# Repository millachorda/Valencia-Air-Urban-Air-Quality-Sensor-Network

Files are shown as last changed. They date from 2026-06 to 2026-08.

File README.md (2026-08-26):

# Valencia Air — Urban Air Quality Sensor Network

Three DIY sensor nodes spread around Valencia, each one measuring the air in a
very different part of the city, all reporting to the same map.

**Live map:** https://valencia-air.milla-chorda.hackclub.app

> **TODO (write this part yourself):** why you started this. What made you want
> to measure the air here instead of just reading the official station data?
> Two or three sentences in your own words — this is the part a reader actually
> remembers, and nobody can write it for you.

---

## Status

Honest state of the project right now:

| Part | State |
|---|---|
| Backend (Flask + SQLite) | Works. Running on Nest. |
| Frontend (Leaflet map + Chart.js) | Works, fed by `/latest` and `/readings/<node>`. |
| Enclosure CAD | Done, parametric, STL + STEP exported. |
| ESP32 firmware | **Not written yet.** The map is currently fed by `backend/test_sender.py`, which posts fake readings. |
| Nodes deployed | 0 of 3. |

So: the whole software side is real and running, the hardware side is designed
but not yet built and flashed.

---

## The three nodes

| Node | Where | Why there |
|---|---|---|
| 1 | City center | Dense residential, narrow streets, not much wind |
| 2 | Periphery | Heavy traffic all day |
| 3 | Beach | Sea air, should be the clean reference |

> **TODO:** replace "City center" / "Periphery" / "Beach" with the actual
> streets or neighbourhoods, and say who is hosting each node (your balcony? a
> friend's window?). Reviewers care that these are real places.

Node 3 sits in constant marine humidity. The PMS5003 counts particles
optically, and above roughly 70 % RH the water on the particles makes them read
bigger than they are — so that node's PM values get corrected using the
humidity from its own BME280 before being stored.

---

## Hardware (per node)

Everything hangs off one ESP32. Four devices share the I2C bus, the particulate
sensor talks UART.

| Component | What it gives | Interface |
|---|---|---|
| ESP32 DevKit (USB-C) | MCU + WiFi | — |
| PMS5003 | PM1.0 / PM2.5 / PM10 in µg/m³ | UART, needs 5 V |
| BME280 | Temperature, humidity, pressure | I2C `0x76` |
| SCD41 | CO₂ in ppm (real NDIR, not estimated) | I2C `0x62` |
| SGP30 | VOC index | I2C `0x58` |
| 0.96" OLED | Shows the readings on the box itself | I2C `0x3C` |
| 5 V / 2 A USB-C supply | Power | — |

Full list with prices and suppliers: [`Hardware/BOM.csv`](Hardware/BOM.csv).

**Note on the two gas sensors:** the SCD41 is the one that measures CO₂
properly. The SGP30 is only there for VOC — its "eCO₂" output is an estimate
derived from VOC and is not used.

## Wiring

| Connection | ESP32 pin |
|---|---|
| SDA (BME280, SCD41, SGP30, OLED) | GPIO21 |
| SCL (BME280, SCD41, SGP30, OLED) | GPIO22 |
| PMS5003 TX → ESP32 | GPIO16 (RX2) |
| PMS5003 RX → ESP32 | GPIO17 (TX2) |
| BME280 / SGP30 / OLED VCC | 3V3 |
| PMS5003 VCC, SCD41 VDD | 5 V (VIN) |
| Everything GND | GND |

Diagram: [`Hardware/CAD/circuit_image.svg`](Hardware/CAD/circuit_image.svg)

---

## Enclosure

A commercial IP65 box (150 × 110 × 70 mm) with three printed parts inside it:
a tray that holds the boards, a bezel for the OLED, and a duct that feeds
outside air to the PMS5003.

Everything lives in [`Hardware/CAD/`](Hardware/CAD):

| File | What it is |
|---|---|
| `valencia_air_enclosure.py` | **Source.** CadQuery script, all dimensions parametric at the top. |
| `mounting_plate.stl` | Print this — interior tray |
| `oled_bezel.stl` | Print this — display frame |
| `pms_duct.stl` | Print this — air duct |
| `valencia_air_node.step` | All three parts in one STEP, positioned as they sit in the box |

To regenerate the STL and STEP files after changing a dimension:

```bash
pip install cadquery
python Hardware/CAD/valencia_air_enclosure.py
```

The parameters marked `[VERIFICAR]` in the script are the ones I could not
confirm against a datasheet — measure your own modules with calipers before
printing, generic boards vary between batches.

The renders in [`Hardware/Images/`](Hardware/Images) are the earlier Tinkercad
mockup, kept only to show how the layout started. The CadQuery script is the
real design.

---

## Assembly

Step by step build instructions, around 2 h per node:
**[`Hardware/ASSEMBLY.md`](Hardware/ASSEMBLY.md)**

---

## Software

### Backend — `backend/`

Flask + SQLite. One table, `readings`, one row per measurement.

```bash
cd backend
pip install flask flask-cors requests
python init_db.py        # creates readings.db
python app.py            # serves on :5000
```

| Route | Method | Does |
|---|---|---|
| `/` | GET | Serves the map |
| `/data` | POST | A node sends a reading (JSON) |
| `/readings` | GET | Everything |
| `/latest` | GET | Last reading of each node — this is what the map markers use |
| `/readings/<node>` | GET | History of one node, for the charts |

With no hardware built yet, you can fill the database with fake readings:

```bash
python backend/test_sender.py
```

### Frontend — `frontend/index.html`

One HTML file. Leaflet for the map, Chart.js for the history panel that opens
when you click a node. No build step, no framework.

### Firmware — not written yet

Planned: Arduino on the ESP32, using `Adafruit_BME280`, `Adafruit_SGP30`,
`Sensirion SCD4x`, `PMS` and `Adafruit_SSD1306`, POSTing JSON to `/data` in the
same shape `test_sender.py` uses.

---

## What's left

- [ ] Write the ESP32 firmware
- [ ] Print the three parts and build node 1
- [ ] Find hosts for nodes 2 and 3
- [ ] Deploy and let it run

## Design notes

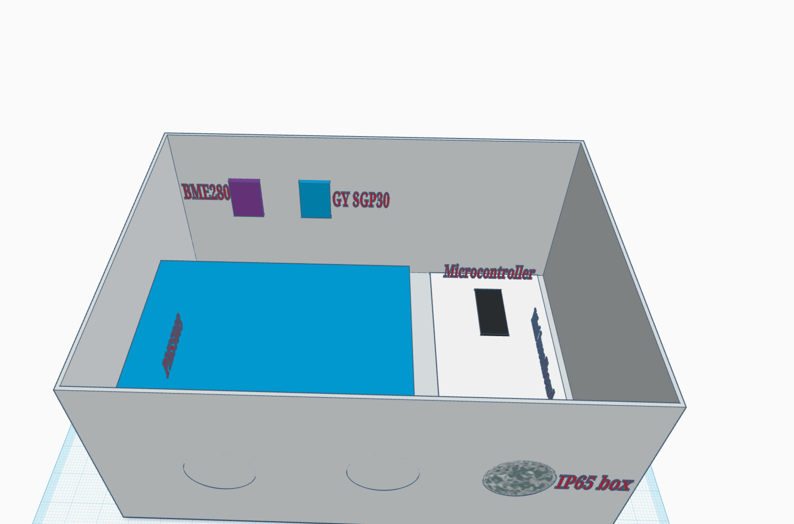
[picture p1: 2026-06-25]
Hardware/Images/Captura de pantalla 2026-06-25 162358.png

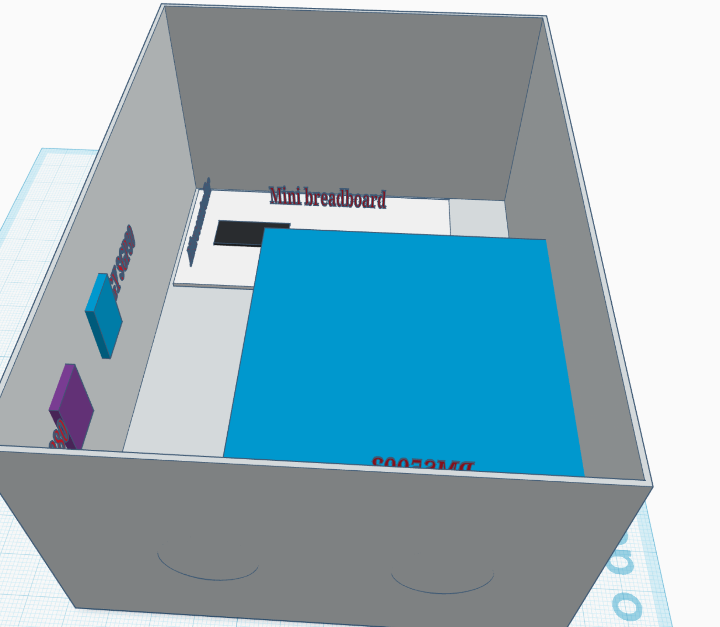
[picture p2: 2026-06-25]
Hardware/Images/Captura de pantalla 2026-06-25 162418.png

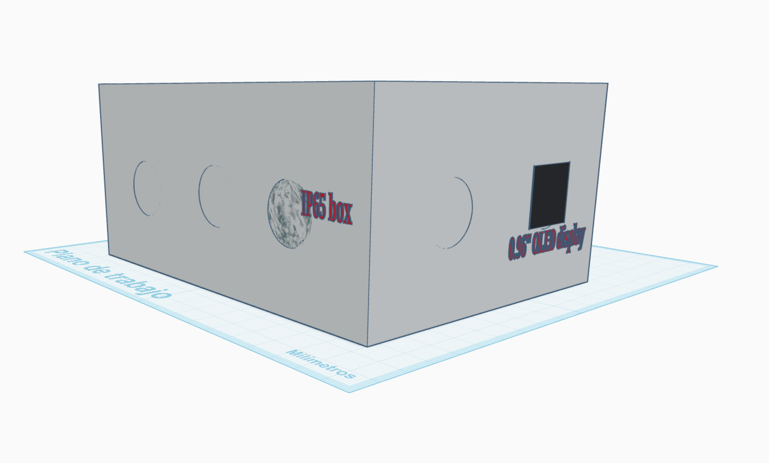
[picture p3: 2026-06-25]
Hardware/Images/Captura de pantalla 2026-06-25 162337.png

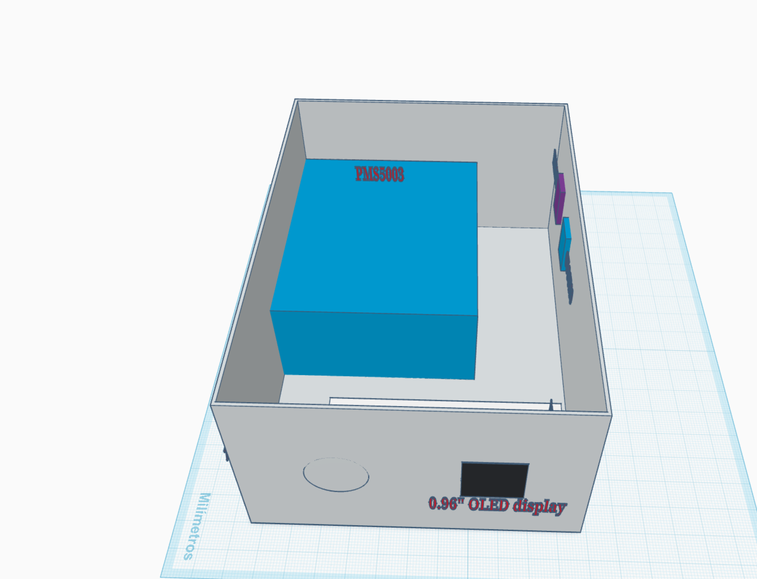
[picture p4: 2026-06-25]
Hardware/Images/Captura de pantalla 2026-06-25 162432.png

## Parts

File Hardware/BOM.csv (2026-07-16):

Component | Quantity | Unit Price (EUR) | Total Price (EUR) | Supplier | Interface | Notes
ESP32 DevKit (USB-C) | 1 pack of 3 | 19.99 | 19.99 | Amazon (ELEGOO 3-pack) | - | Microcontroller + WiFi (one per node)
PMS5003 | 3 | 29.54 | 88.62 | Amazon | UART(5V) | Particulate matter sensor (PM1.0 / PM2.5 / PM10) (one per node)
BME280 | 3 | 15.97 | 47.91 | Amazon | I2C 0x76 | Temperature / Humidity / Pressure sensor (one per node)
SCD41 | 3 | 19.99 | 59.97 | Amazon (Hailege) | I2C 0x62 | True NDIR CO2 sensor (one per node)
SGP30 | 3 | 18.14 | 54.42 | Amazon | I2C 0x58 | VOC sensor (one per node)
0.96 OLED display | 3 | 6.15 | 18.45 | Amazon (RUIZHI 3-pack) | I2C 0x3C | Local readings display (one per node)
USB-C power supply 5V/2A | 3 | 8.45 | 25.35 | Amazon | - | Power supply (one per node)
Breadboard + Dupont wires kit | 3 | 13.49 | 40.47 | Amazon | - | Connections (one per node)
IP65 waterproof enclosure | 3 | 12.31 | 36.93 | Amazon (CPROSP) | - | 150x110x70mm with cable glands (one per node)
Neutral silicone sealant | 1 | 5.66 | 5.66 | Amazon (SIKA) | - | Seals the enclosure and the OLED window
PTFE vent membrane | 3 | 2.50 | 7.50 | Amazon | - | Air inlet/outlet for PMS5003 - blocks water
3D printed parts | 3 | 3.00 | 9.00 | Self-printed PLA/PETG | - | Mounting plate + OLED bezel + PMS duct (see Hardware/CAD)
TOTAL |  |  | 414.27

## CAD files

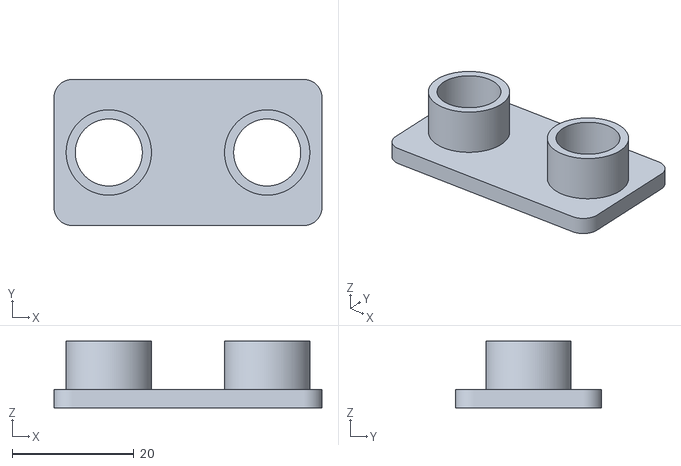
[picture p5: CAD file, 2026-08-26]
Hardware/CAD/pms_duct.stl
44.0 x 24.0 x 11.0

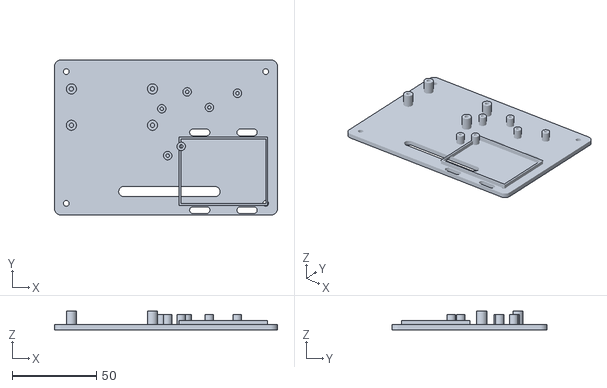
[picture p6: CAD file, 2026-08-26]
Hardware/CAD/mounting_plate.stl
132.0 x 92.0 x 11.0

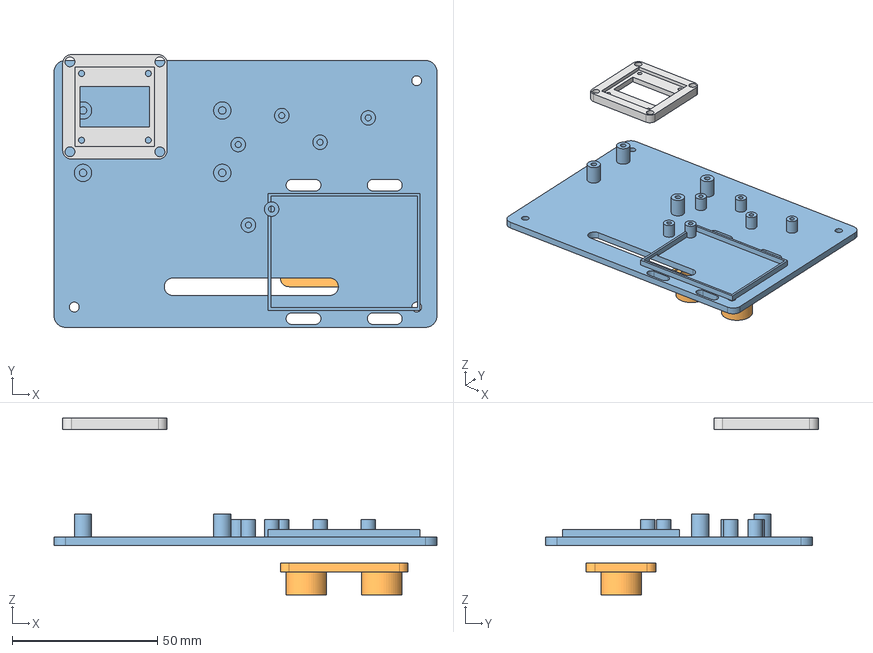
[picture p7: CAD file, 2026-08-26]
Hardware/CAD/valencia_air_node.step
132.0 x 94.0 x 61.0 mm
mounting_plate
oled_bezel
pms_duct

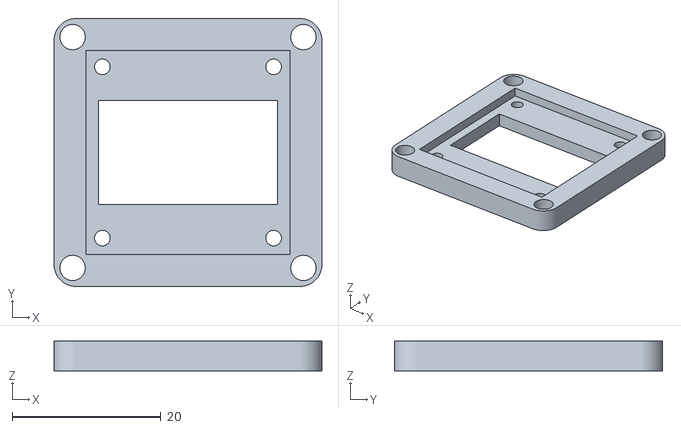
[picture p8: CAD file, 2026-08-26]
Hardware/CAD/oled_bezel.stl
36.0 x 36.0 x 4.00

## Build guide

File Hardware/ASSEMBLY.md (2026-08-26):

# Assembly Instructions — Valencia Air Node

Approximate build time: ~2 h per node (plus print time and silicone cure).
All three nodes are identical.

---

## 0. Parts and tools

**From the BOM:** ESP32 DevKit, PMS5003 + JST cable, SCD41, SGP30, BME280,
OLED, IP65 enclosure, USB-C PSU, Dupont wires, PTFE membrane, neutral silicone.

**3D printed** (see `Hardware/CAD/`, PLA or PETG, 0.2 mm layers, 30% infill —
PETG preferred for the coastal node, it handles UV and heat better):
- `mounting_plate.stl` — interior tray
- `oled_bezel.stl` — display frame
- `pms_duct.stl` — PMS5003 air duct

**Tools:** soldering iron, 20 mm hole saw (included with the CPROSP box),
3 mm drill bit, screwdriver, calipers, multimeter, zip ties.

---

## 1. Verify dimensions before printing

The CAD is parametric. Measure your actual modules with calipers and update the
`[VERIFICAR]` parameters at the top of `valencia_air_enclosure.py`, then re-run
it. Generic modules vary between batches — do not assume the defaults fit.

```bash
pip install cadquery
python valencia_air_enclosure.py
```

---

## 2. Solder headers

Solder the pin headers to the SCD41, SGP30 and BME280. Joints must be shiny and
cone-shaped against the pad. A cold joint (dull, blobby) reads as a dead module
and is very hard to diagnose later.

---

## 3. Bench test before enclosing

Wire everything on the breadboard first, per `Hardware/CAD/circuit_image.svg`:

| From | To |
|---|-----|
| SCD41 VDD | ESP32 VIN (5 V) |
| SGP30 VIN / BME280 VIN / OLED VCC | ESP32 3V3 |
| PMS5003 VCC | ESP32 VIN (5 V) |
| All GND | ESP32 GND |
| All SDA | GPIO21 |
| All SCL | GPIO22 |
| PMS5003 TX | GPIO16 (RX2) |
| PMS5003 RX | GPIO17 (TX2) |
| PMS5003 SET / RST | leave unconnected |

Flash the firmware and open the serial monitor at 115200 baud. The I2C scanner
must report **four devices**: `0x3C`, `0x58`, `0x62`, `0x76`. Do not proceed
until all four appear — diagnosing a missing sensor inside a sealed box is
significantly harder.

Sanity checks: SCD41 should read ~420 ppm in open air and climb above 1000 ppm
if you breathe near it. The PMS5003 fan must be audible.

---

## 4. Drill the enclosure

**Bottom face** (ports face **down** so rain cannot enter):
- 2 holes ⌀12 mm, 26 mm apart, aligned with the PMS5003 inlet and outlet.

**Lid:**
- Rectangular window 24 × 14 mm for the OLED.
- 4 holes ⌀3 mm for the bezel screws.

**Side face:**
- 1 gland for the USB-C power cable.
- 1 gland for the BME280 cable (see step 6).

---

## 5. Mount the tray

1. Screw the ESP32 onto its four posts (M3 self-tapping).
2. Screw the SCD41 and SGP30 onto their posts (M2.5).
3. Seat the PMS5003 inside its rim and secure it with two zip ties through the
   slots.
4. Screw the tray to the enclosure bosses (M3).

---

## 6. Mount the BME280 OUTSIDE the box

This is not optional. Inside a closed enclosure the BME280 measures the box's
own temperature, not ambient air — under direct sun that reads up to 10 °C high,
which corrupts the humidity correction applied to the PM readings at Node 3.

Run its 4 wires out through a cable gland and mount it in shade under the box,
in a small vented radiation shield. Seal the gland with neutral silicone.

---

## 7. Air duct

1. Glue `pms_duct` to the inside of the bottom face with neutral silicone, tubes
   aligned with the two drilled holes.
2. Press one PTFE membrane disc into each pocket on the outer face.
3. **Seal the perimeter between the PMS5003 and the duct.** If air can leak
   around it, the sensor recirculates its own exhaust and measures the same air
   repeatedly instead of the atmosphere.

---

## 8. OLED window

1. Cut a 30 × 20 mm piece of clear polycarbonate or acrylic.
2. Silicone it over the window opening **from the inside**.
3. Seat the OLED PCB in the bezel pocket and screw the bezel to the lid.

The window is **sealed**. It is not a vent — all airflow goes through the duct.

---

## 9. Final assembly

1. Route and secure all cables away from the PMS5003 fan.
2. Tighten every gland.
3. Apply neutral silicone to all penetrations and let it cure **24 h before
   deployment**.
4. Close the lid with the four original screws.

---

## 10. Deployment

Mount with the air duct facing down, ideally under an eave or small visor,
1.5–3 m above ground, away from direct exhaust sources. Confirm WiFi RSSI is
better than −75 dBm at the final location — the serial log prints it at boot.

**Ingress rating note:** drilling the air duct means the enclosure is no longer
strictly IP65. With downward-facing ports and PTFE membranes it is effectively
rain-protected (~IP54). This is standard practice for outdoor air quality
stations — a particulate sensor in a truly sealed box measures nothing.

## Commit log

2026-06-22 Create Node 1 wiring.svg
2026-06-22 Añadir esquemas de cableado de los 3 nodos
2026-06-22 Update Node 1 wiring diagram and add Node 2 and Node 3 wiring diagrams
    - Enhanced Node 1 wiring diagram with improved layout and connections.
    - Added Node 2 wiring diagram, maintaining consistency with Node 1.
    - Introduced Node 3 wiring diagram, including details for weatherproof enclosure.
2026-06-25 Update README and BOM: Revise descriptions, enhance clarity, and add detailed component list for sensor nodes
    [BOM.csv]
2026-06-25 Update BOM: Correct quantity and total price for ESP32 DevKit and BME280 components
    [BOM.csv]
2026-06-25 Add BOM.csv: Create new Bill of Materials file with component details
    [BOM.csv]
2026-06-25 Refactor code structure for improved readability and maintainability
    [Node.stl]
